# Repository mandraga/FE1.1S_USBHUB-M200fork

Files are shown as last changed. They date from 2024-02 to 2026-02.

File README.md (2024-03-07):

# FE1.1S_USBHUB

## Description:
This is an working USB HUB using the FE1.1S ic. It has low transfer speed, but it\`s working.<br>
The board has 5 led\`s(one to show each port activity and one for general working), 4 decoupling capacitors (for the 1.8V, 3.3V and 5V internal regulators), an 2.7kohm (+- 1%) resistor between pin 14 and GND and an  12MHz oscilator between pins 2 and 3.

<table>
  <tr>
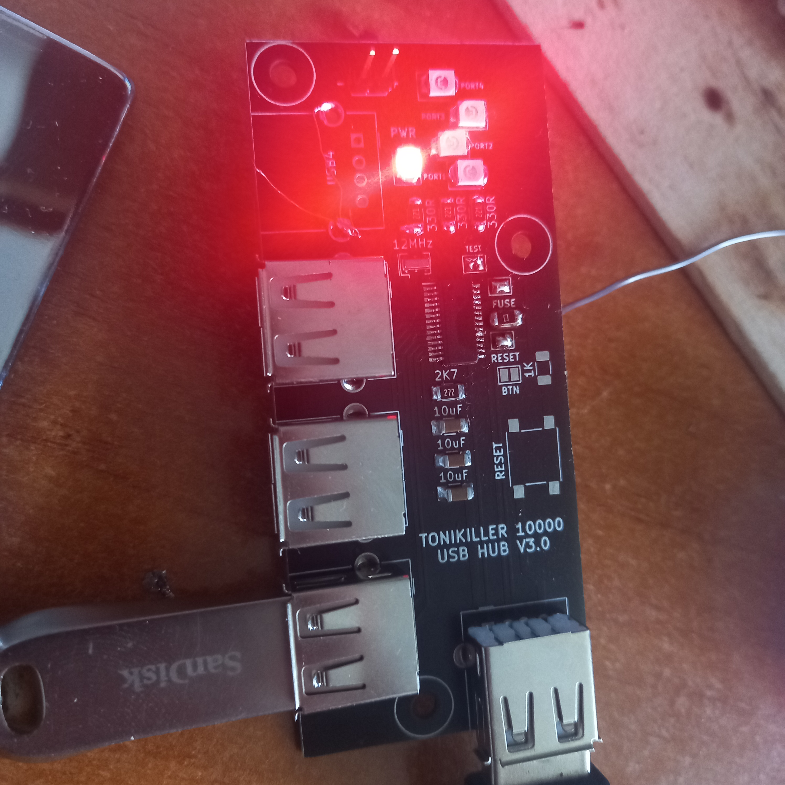
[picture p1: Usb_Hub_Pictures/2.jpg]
    <td></td>
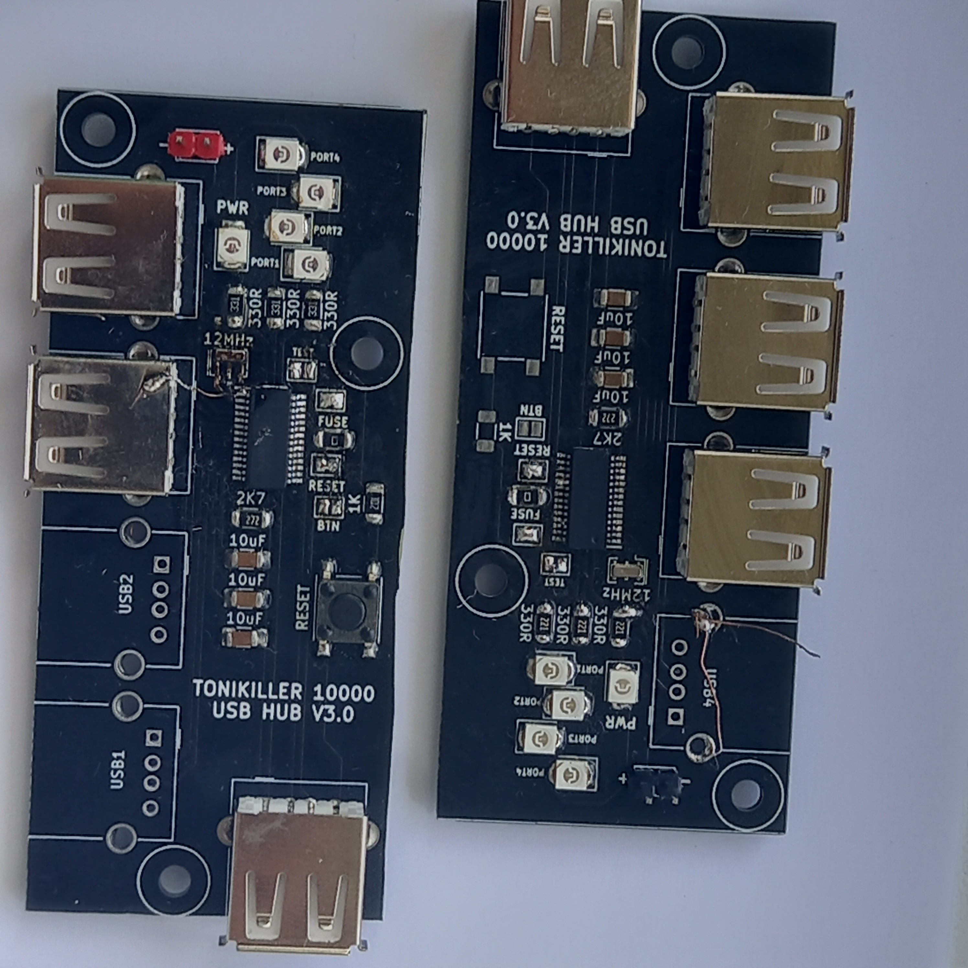
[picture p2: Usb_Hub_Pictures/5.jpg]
    <td></td>
  </tr>
</table>

## My schematic


## Results:
As you can see, the USB hub is recognised and it\`s working. 
One ["mistake"](https://github.com/Tonikiller10000/FE1.1S_USBHUB/blob/main/Usb_Hub_Pictures/12.jpg) I connected the GND trouth the USB ports mounting pins, witch needs that all the ports to be connected, or to connect the mounting boles of the ports with an wire.
The thing I don\`t like is it\`s transfer speed, but in the future I think I can experiment with it to make it work at the USB2.0 full speed(480MHz) and to use it`s pins to be controlled by a microcontroller.
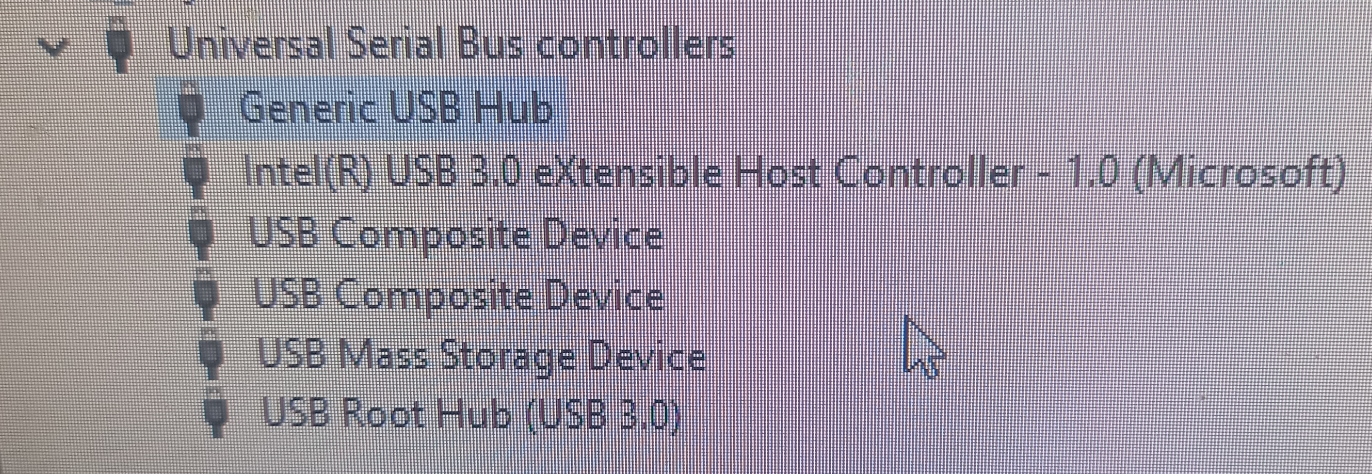
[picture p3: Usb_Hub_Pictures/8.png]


## Links:
- FE1.1sDatasheet: https://cdn-shop.adafruit.com/product-files/2991/FE1.1s%20Data%20Sheet%20(Rev.%201.0).pdf
- The schematic from witch I did mine: https://github.com/Tonikiller10000/FE1.1S_USBHUB/blob/main/Usb_Hub_Pictures/3.png

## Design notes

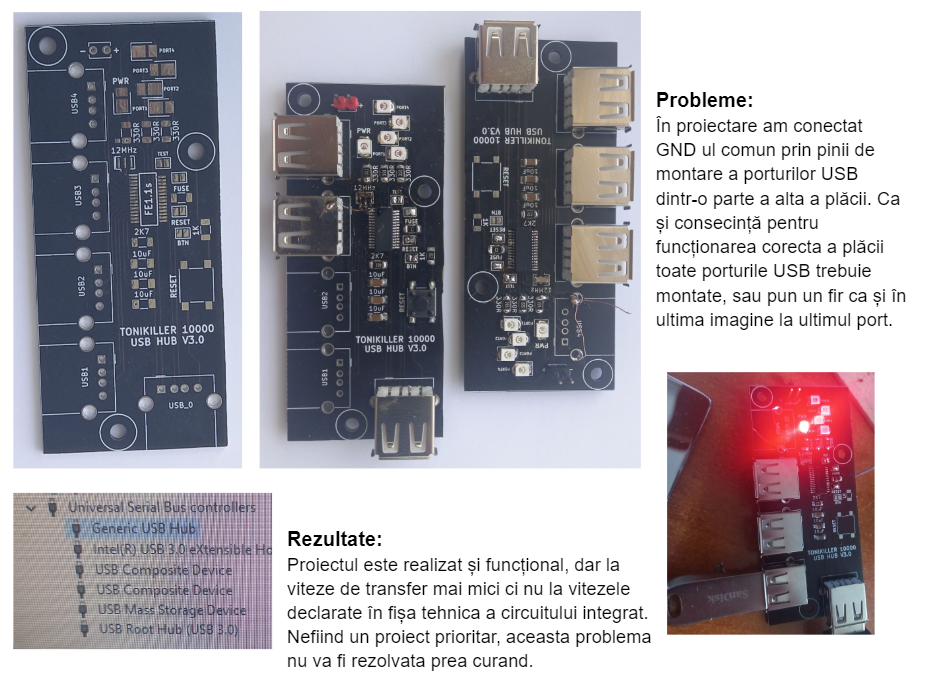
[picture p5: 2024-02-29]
Usb_Hub_Pictures/Screenshot 2023-10-15 130018.png

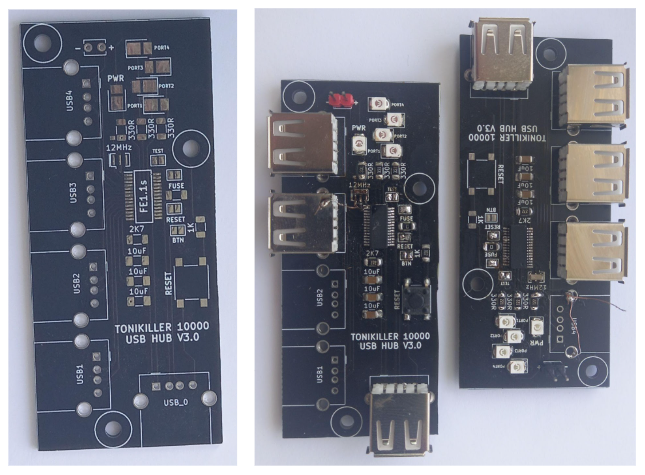
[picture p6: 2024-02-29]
Usb_Hub_Pictures/Screenshot 2023-11-07 202101.png

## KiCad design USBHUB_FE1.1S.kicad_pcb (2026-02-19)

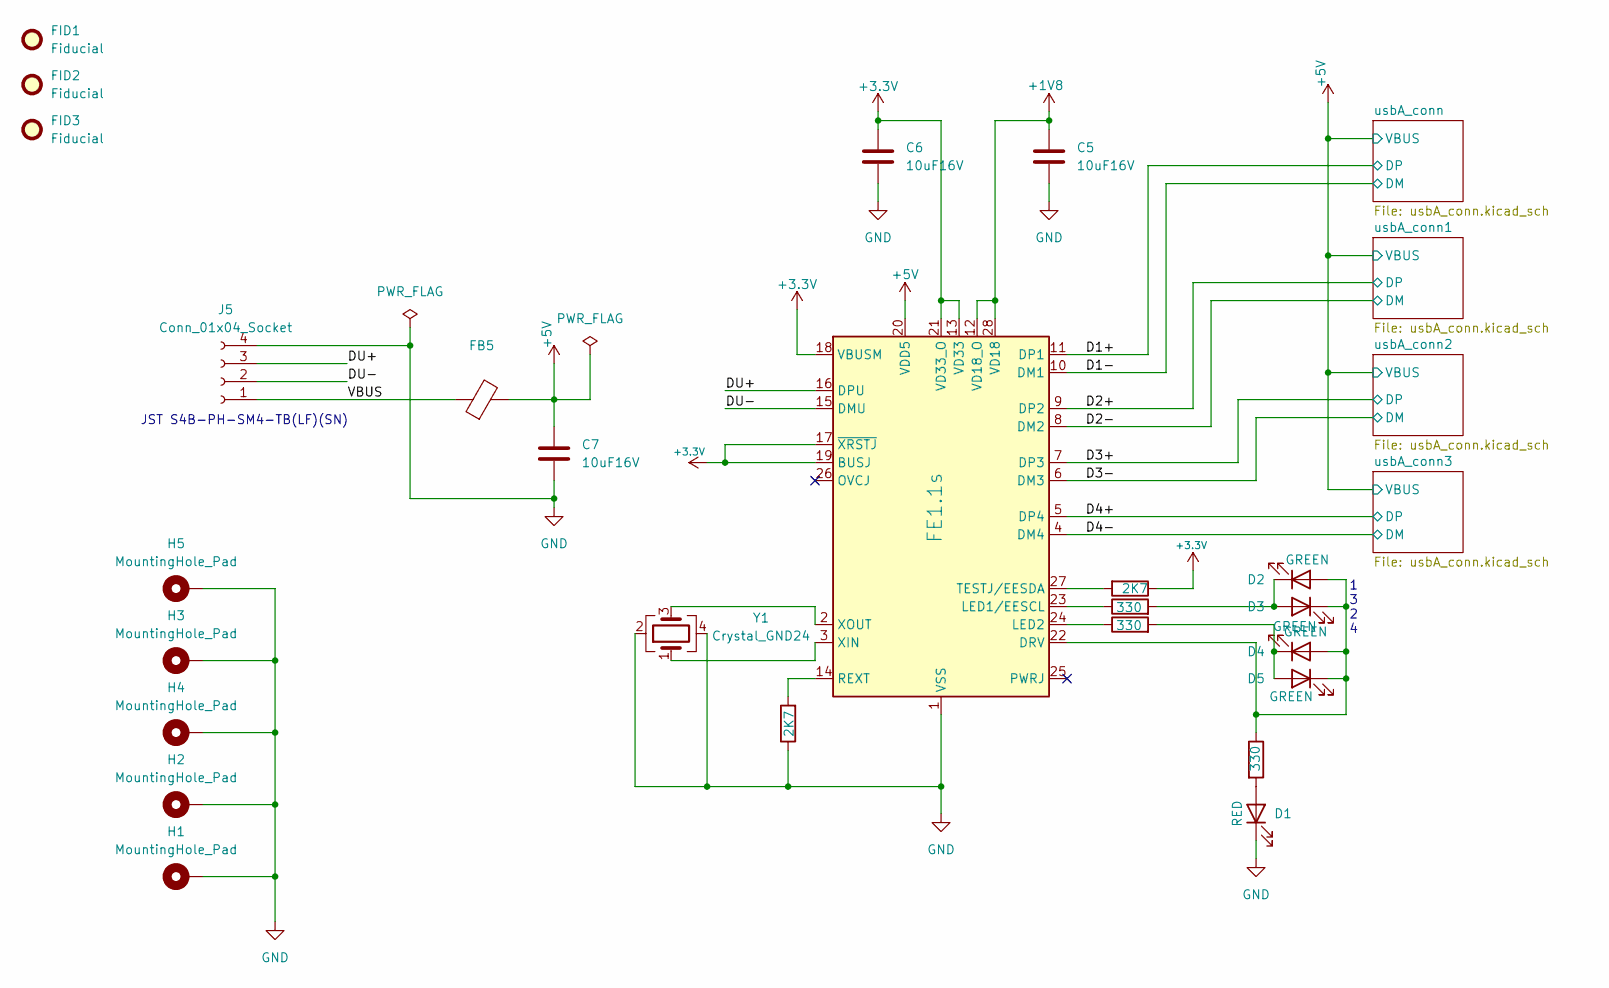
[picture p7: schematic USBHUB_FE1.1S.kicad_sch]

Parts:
C5, C6, C7: 10uF16V; C_0805_2012Metric
D1: RED; LED_0805_2012Metric
D2, D3, D4, D5: GREEN; LED_0805_2012Metric
FB5: FerriteBead; L_0805_2012Metric; FarnellRef 2800851RL
FID1, FID2, FID3: Fiducial; Fiducial_0.5mm_Mask1.5mm
H1, H2, H3, H4, H5: MountingHole_Pad; MountingHole_3.2mm_M3_DIN965_Pad_TopBottom
J5: Conn_01x04_Socket; JST_PH_S4B-PH-SM4-TB_1x04-1MP_P2.00mm_Horizontal; FarnellRef 9492631
R1, R4, R5: 330; R_0805_2012Metric
R2, R3: 2K7; R_0805_2012Metric
U1: FE1.1s; SSOP-28_3.9x9.9mm_P0.635mm
Y1: Crystal_GND24; Crystal_SMD_3225-4Pin_3.2x2.5mm; FarnellRef 2853914RL

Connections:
+1V8: C5.1, U1.12 (VD18_O), U1.28 (VD18)
+3.3V: C6.1, R2.1, U1.13 (VD33), U1.17 (~XRSTJ), U1.18 (VBUSM), U1.19 (BUSJ), U1.21 (VD33_O)
+5V: C7.1, FB5.2, U1.20 (VDD5); also elsewhere on the board
/D1+: U1.11 (DP1); also elsewhere on the board
/D1-: U1.10 (DM1); also elsewhere on the board
/D2+: U1.9 (DP2); also elsewhere on the board
/D2-: U1.8 (DM2); also elsewhere on the board
/D3+: U1.7 (DP3); also elsewhere on the board
/D3-: U1.6 (DM3); also elsewhere on the board
/D4+: U1.5 (DP4); also elsewhere on the board
/D4-: U1.4 (DM4); also elsewhere on the board
/DU+: J5.3, U1.16 (DPU)
/DU-: J5.2, U1.15 (DMU)
/VBUS: FB5.1, J5.1
GND: C5.2, C6.2, C7.2, D1.1 (K), H1.1, H2.1, H3.1, H4.1, H5.1, J5.4, R3.1, U1.1 (VSS), Y1.2, Y1.4; also elsewhere on the board
unnamed: D1.2 (A), R1.2
unnamed: D2.2 (A), D3.1 (K), D4.2 (A), D5.1 (K), R1.1, U1.22 (DRV)
unnamed: D2.1 (K), D3.2 (A), R4.2
unnamed: D4.1 (K), D5.2 (A), R5.2
unnamed: R4.1, U1.23 (LED1/EESCL)
unnamed: R5.1, U1.24 (LED2)
unnamed: R3.2, U1.14 (REXT)
unnamed: R2.2, U1.27 (TESTJ/EESDA)
unnamed: U1.3 (XIN), Y1.1
unnamed: U1.2 (XOUT), Y1.3

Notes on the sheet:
1 3 2 4
JST S4B-PH-SM4-TB(LF)(SN)

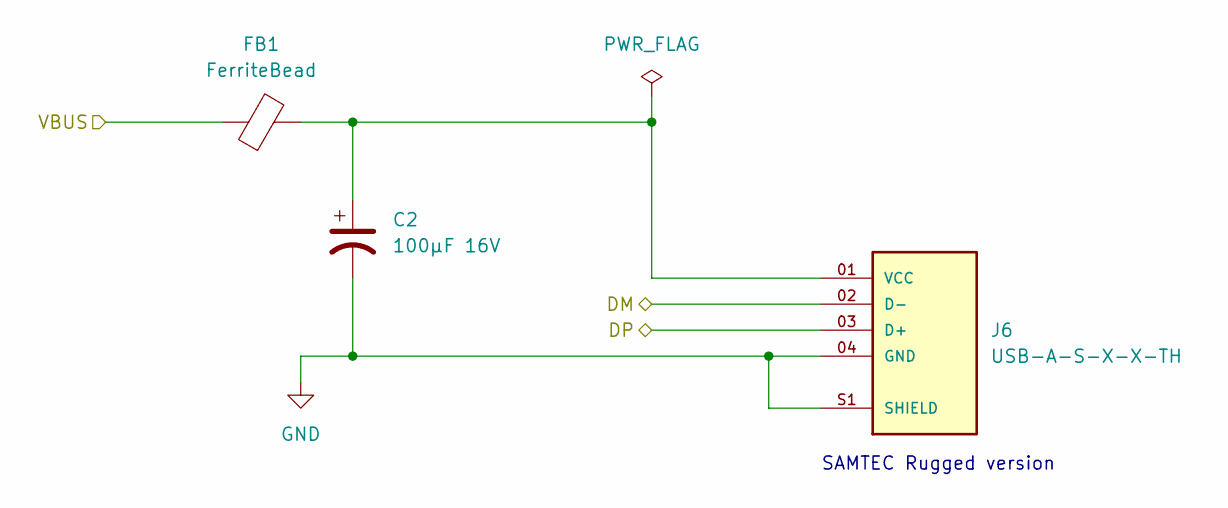
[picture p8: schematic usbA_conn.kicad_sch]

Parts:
C2: 100µF 16V; CP_Elec_6.3x5.4; FarnellRef 2611356
FB1: FerriteBead; L_0805_2012Metric; FarnellRef 2800851RL
J6: USB-A-S-X-X-TH; SAMTEC_USB-A-S-X-X-TH; PARTREV R

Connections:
+5V: FB1.1; also elsewhere on the board
/D1+: J6.03 (D+); also elsewhere on the board
/D1-: J6.02 (D-); also elsewhere on the board
GND: C2.2, J6.04 (GND), J6.S1 (SHIELD), J6.S2 (SHIELD); also elsewhere on the board

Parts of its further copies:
C1, C3, C4: 100µF 16V; CP_Elec_6.3x5.4; FarnellRef 2611356
FB2, FB3, FB4: FerriteBead; L_0805_2012Metric; FarnellRef 2800851RL
J7, J8, J9: USB-A-S-X-X-TH; SAMTEC_USB-A-S-X-X-TH; PARTREV R

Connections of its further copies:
+5V: FB2.1, FB3.1, FB4.1; also elsewhere on the board
/D2+: J7.03 (D+); also elsewhere on the board
/D2-: J7.02 (D-); also elsewhere on the board
/D3+: J8.03 (D+); also elsewhere on the board
/D3-: J8.02 (D-); also elsewhere on the board
/D4+: J9.03 (D+); also elsewhere on the board
/D4-: J9.02 (D-); also elsewhere on the board
GND: C1.2, C3.2, C4.2, J7.04 (GND), J7.S1 (SHIELD), J7.S2 (SHIELD), J8.04 (GND), J8.S1 (SHIELD), J8.S2 (SHIELD), J9.04 (GND), J9.S1 (SHIELD), J9.S2 (SHIELD); also elsewhere on the board
unnamed: C3.1, FB3.2, J8.01 (VCC)
unnamed: C4.1, FB4.2, J9.01 (VCC)

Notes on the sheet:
SAMTEC Rugged version

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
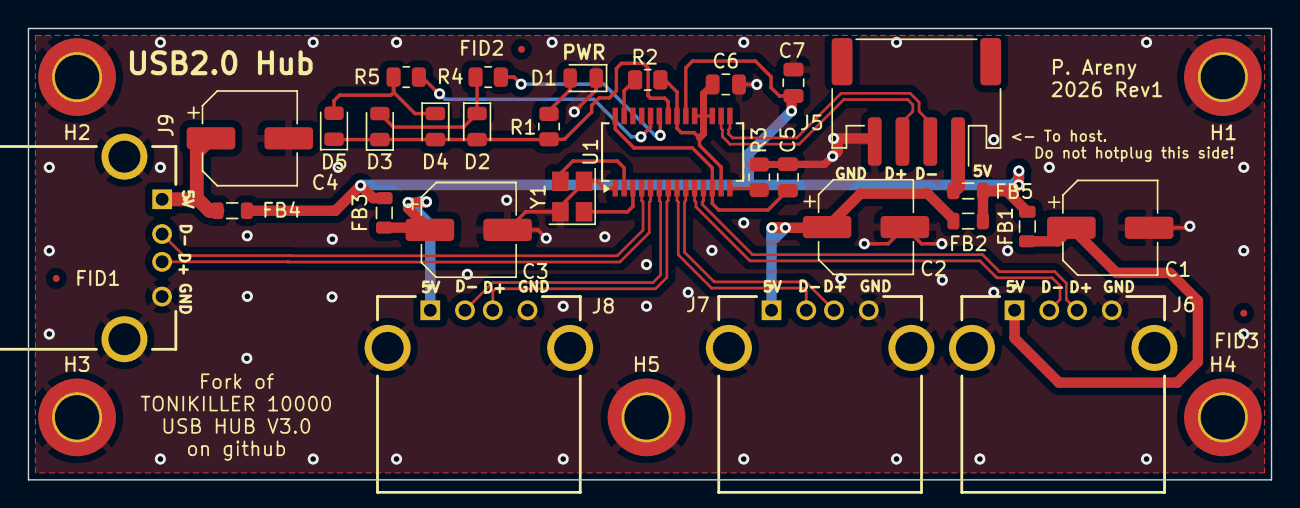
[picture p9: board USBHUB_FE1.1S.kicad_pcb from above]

Board: 2 copper layers, 89.5 x 32.5 mm, 37 parts (0 on the bottom side), 29 nets.

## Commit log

2026-02-16 Adds capacitors and ferrite beads
    Also a Fatrnell BOM.
    [USBHUB_FE1.1S.kicad_sch, usbA_conn.kicad_sch]
2026-02-17 Finished schematic
    The USB-A connector foortprint, 3D model, and symbol comes from Snap
    EDA.
    [USBHUB_FE1.1S.kicad_sch, usbA_conn.kicad_sch]
2026-02-17 ERC pass but one ground pin on th eUSB-A connector.
    [USBHUB_FE1.1S.kicad_sch, usbA_conn.kicad_sch]
2026-02-17 Routed, Rev1
    [USBHUB_FE1.1S.kicad_pcb, USBHUB_FE1.1S.kicad_sch, usbA_conn.kicad_sch]
2026-02-17 Reordering the leds on the board.
    They should be in the same order as the ports.
    [USBHUB_FE1.1S.kicad_pcb, USBHUB_FE1.1S.kicad_sch]
2026-02-19 Puts port on the side
    [USBHUB_FE1.1S.kicad_pcb]
